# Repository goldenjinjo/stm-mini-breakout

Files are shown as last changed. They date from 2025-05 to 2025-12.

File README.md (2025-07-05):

# stm-mini-breakout
Breakout board for STM32H723ZGT6 MCU. Powered and programmed via USB C (FS). WIP.

Demonstration board for high-powered STM32s. 

## Schematics

# MCU
HX‑1 Schematic

# Communication and Power
HX-1 Communication and Power

# Filtering, HSE Clock and Mounting Holes
HX-1 Filtering, Clock and Mounting Holes

## PCB Layout
<p align="center">
HX-1 PCB Layout
</p>

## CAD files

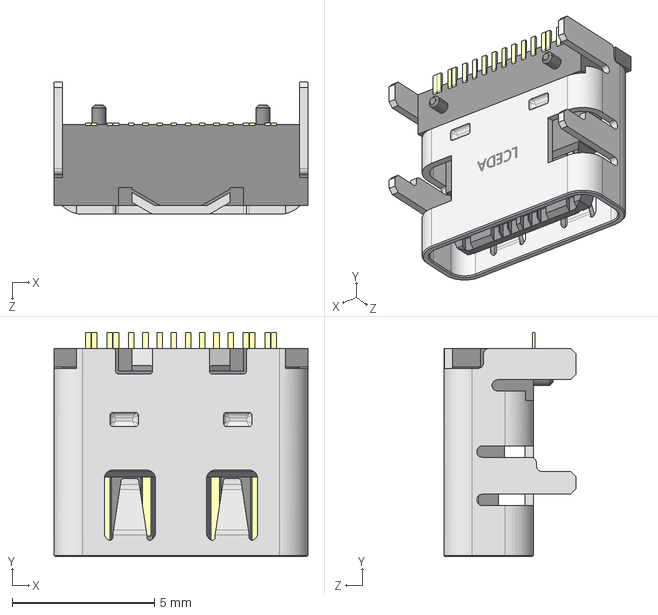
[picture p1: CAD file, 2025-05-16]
HX-1/component_libraries/3D_models/USB-C-SMD_G-SWITCH_GT-USB-7010ASV.step
8.94 x 7.90 x 4.66 mm

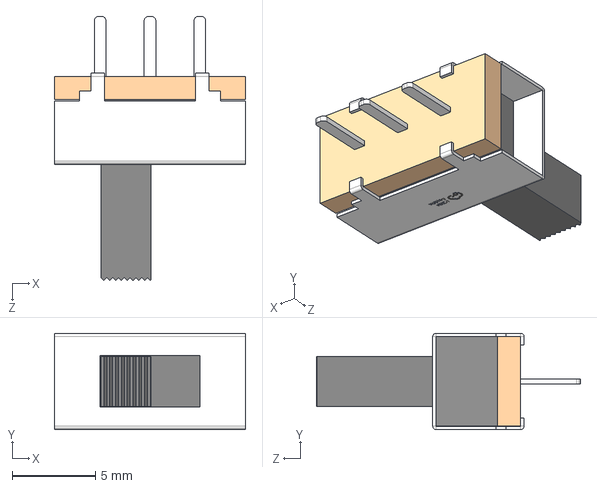
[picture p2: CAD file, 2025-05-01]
HX-1/component_libraries/3D_models/SW-TH_G-SWITCH_SS-12F20-G070.step
11.5 x 5.81 x 15.9 mm

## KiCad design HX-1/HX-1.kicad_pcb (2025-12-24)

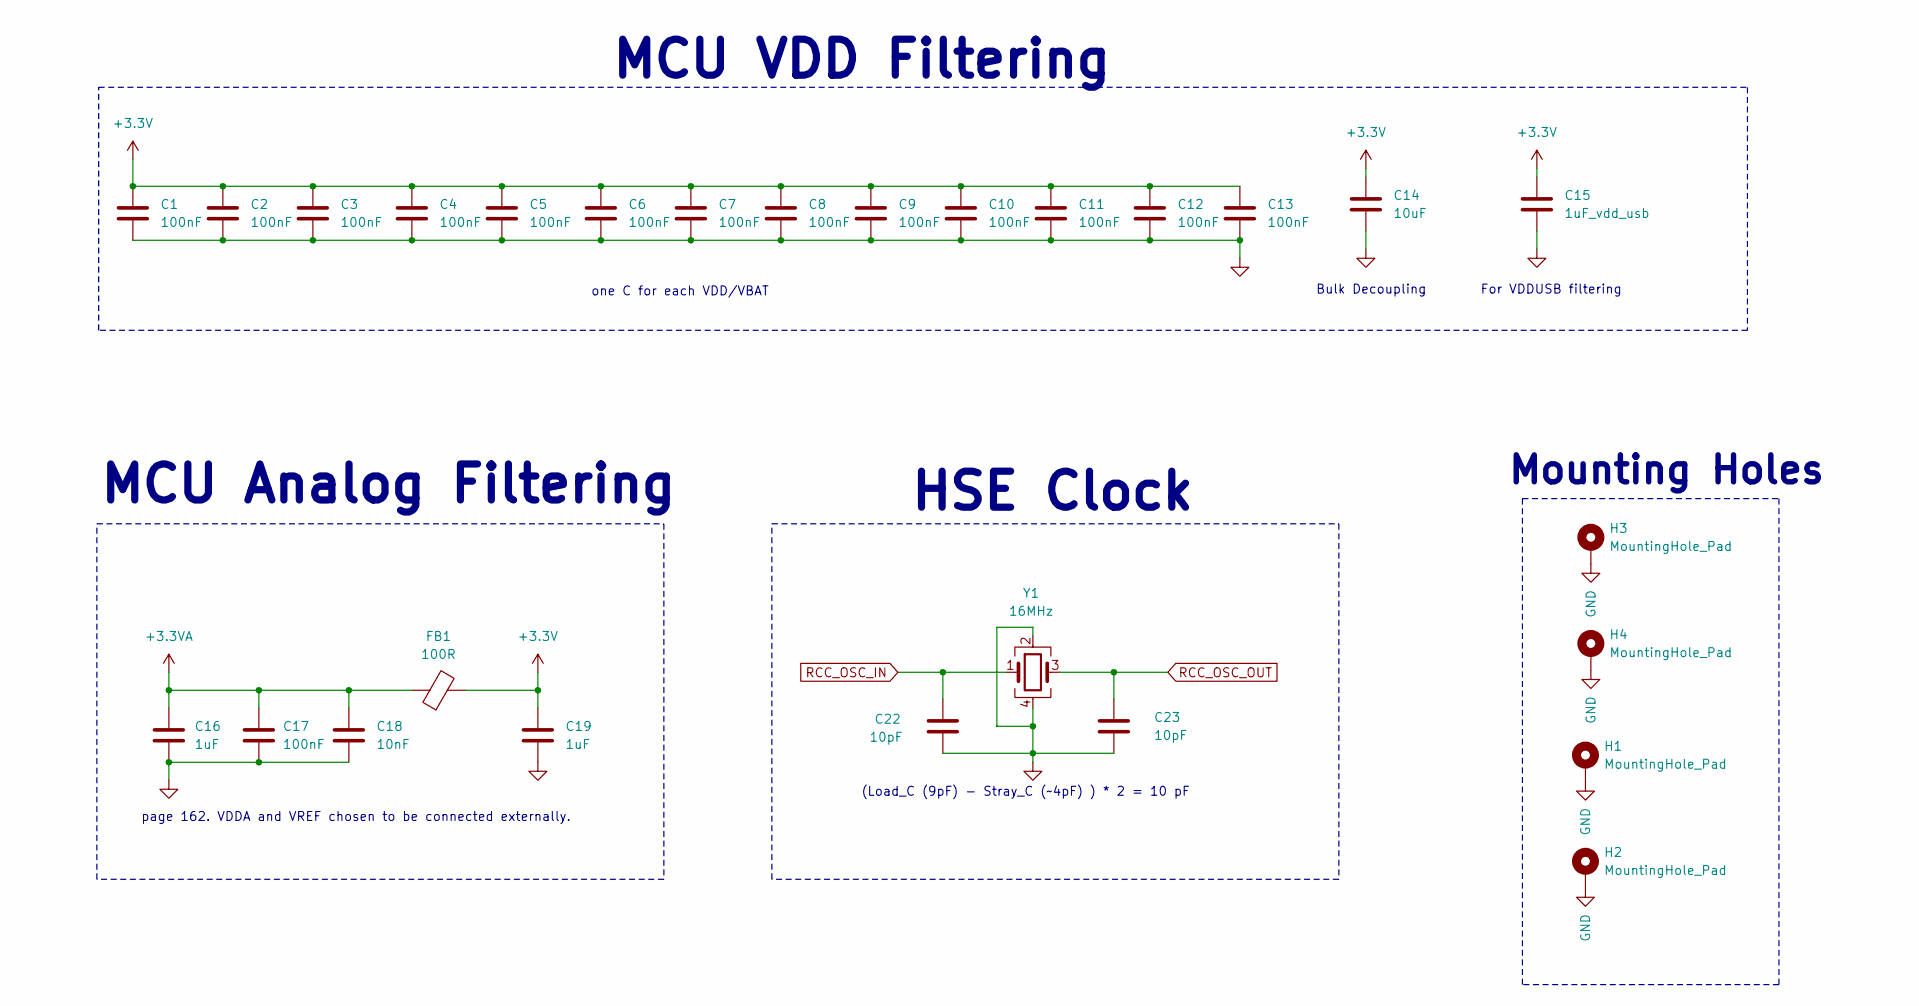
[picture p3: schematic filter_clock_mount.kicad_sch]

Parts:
C1, C2, C3, C4, C5, C6, C7, C8, C9, C10, C11, C12, C13, C17: 100nF; C_0402_1005Metric; LCSC PN C1525
C14: 10uF; C_0603_1608Metric; LCSC PN C19702
C15: 1uF_vdd_usb; C_0603_1608Metric; LCSC PN C15849
C16, C19: 1uF; C_0402_1005Metric; LCSC PN C52923
C18: 10nF; C_0603_1608Metric; LCSC PN C173276
C22, C23: 10pF; C_0603_1608Metric; LCSC PN C1634
FB1: 100R; R_0805_2012Metric; LCSC PN C1015
H1, H2, H3, H4: MountingHole_Pad; MountingHole_3.2mm_M3_Pad
Y1: 16MHz; Crystal_SMD_3225-4Pin_3.2x2.5mm; LCSC PN C13738

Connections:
+3.3V: C1.1, C2.1, C3.1, C4.1, C5.1, C6.1, C7.1, C8.1, C9.1, C10.1, C11.1, C12.1, C13.1, C14.1, C15.1, C19.1, FB1.2; also elsewhere on the board
+3.3VA: C16.1, C17.1, C18.1, FB1.1; also elsewhere on the board
GND: C1.2, C2.2, C3.2, C4.2, C5.2, C6.2, C7.2, C8.2, C9.2, C10.2, C11.2, C12.2, C13.2, C14.2, C15.2, C16.2, C17.2, C18.2, C19.2, C22.1, C23.2, H1.1, H2.1, H3.1, H4.1, Y1.2, Y1.4; also elsewhere on the board
RCC_OSC_IN: C22.2, Y1.1; also elsewhere on the board
RCC_OSC_OUT: C23.1, Y1.3; also elsewhere on the board

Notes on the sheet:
Bulk Decoupling
MCU Analog Filtering
page 162. VDDA and VREF chosen to be connected externally.
(Load_C (9pF) - Stray_C (~4pF) ) * 2 = 10 pF
one C for each VDD/VBAT
For VDDUSB filtering
HSE Clock
MCU VDD Filtering
Mounting Holes

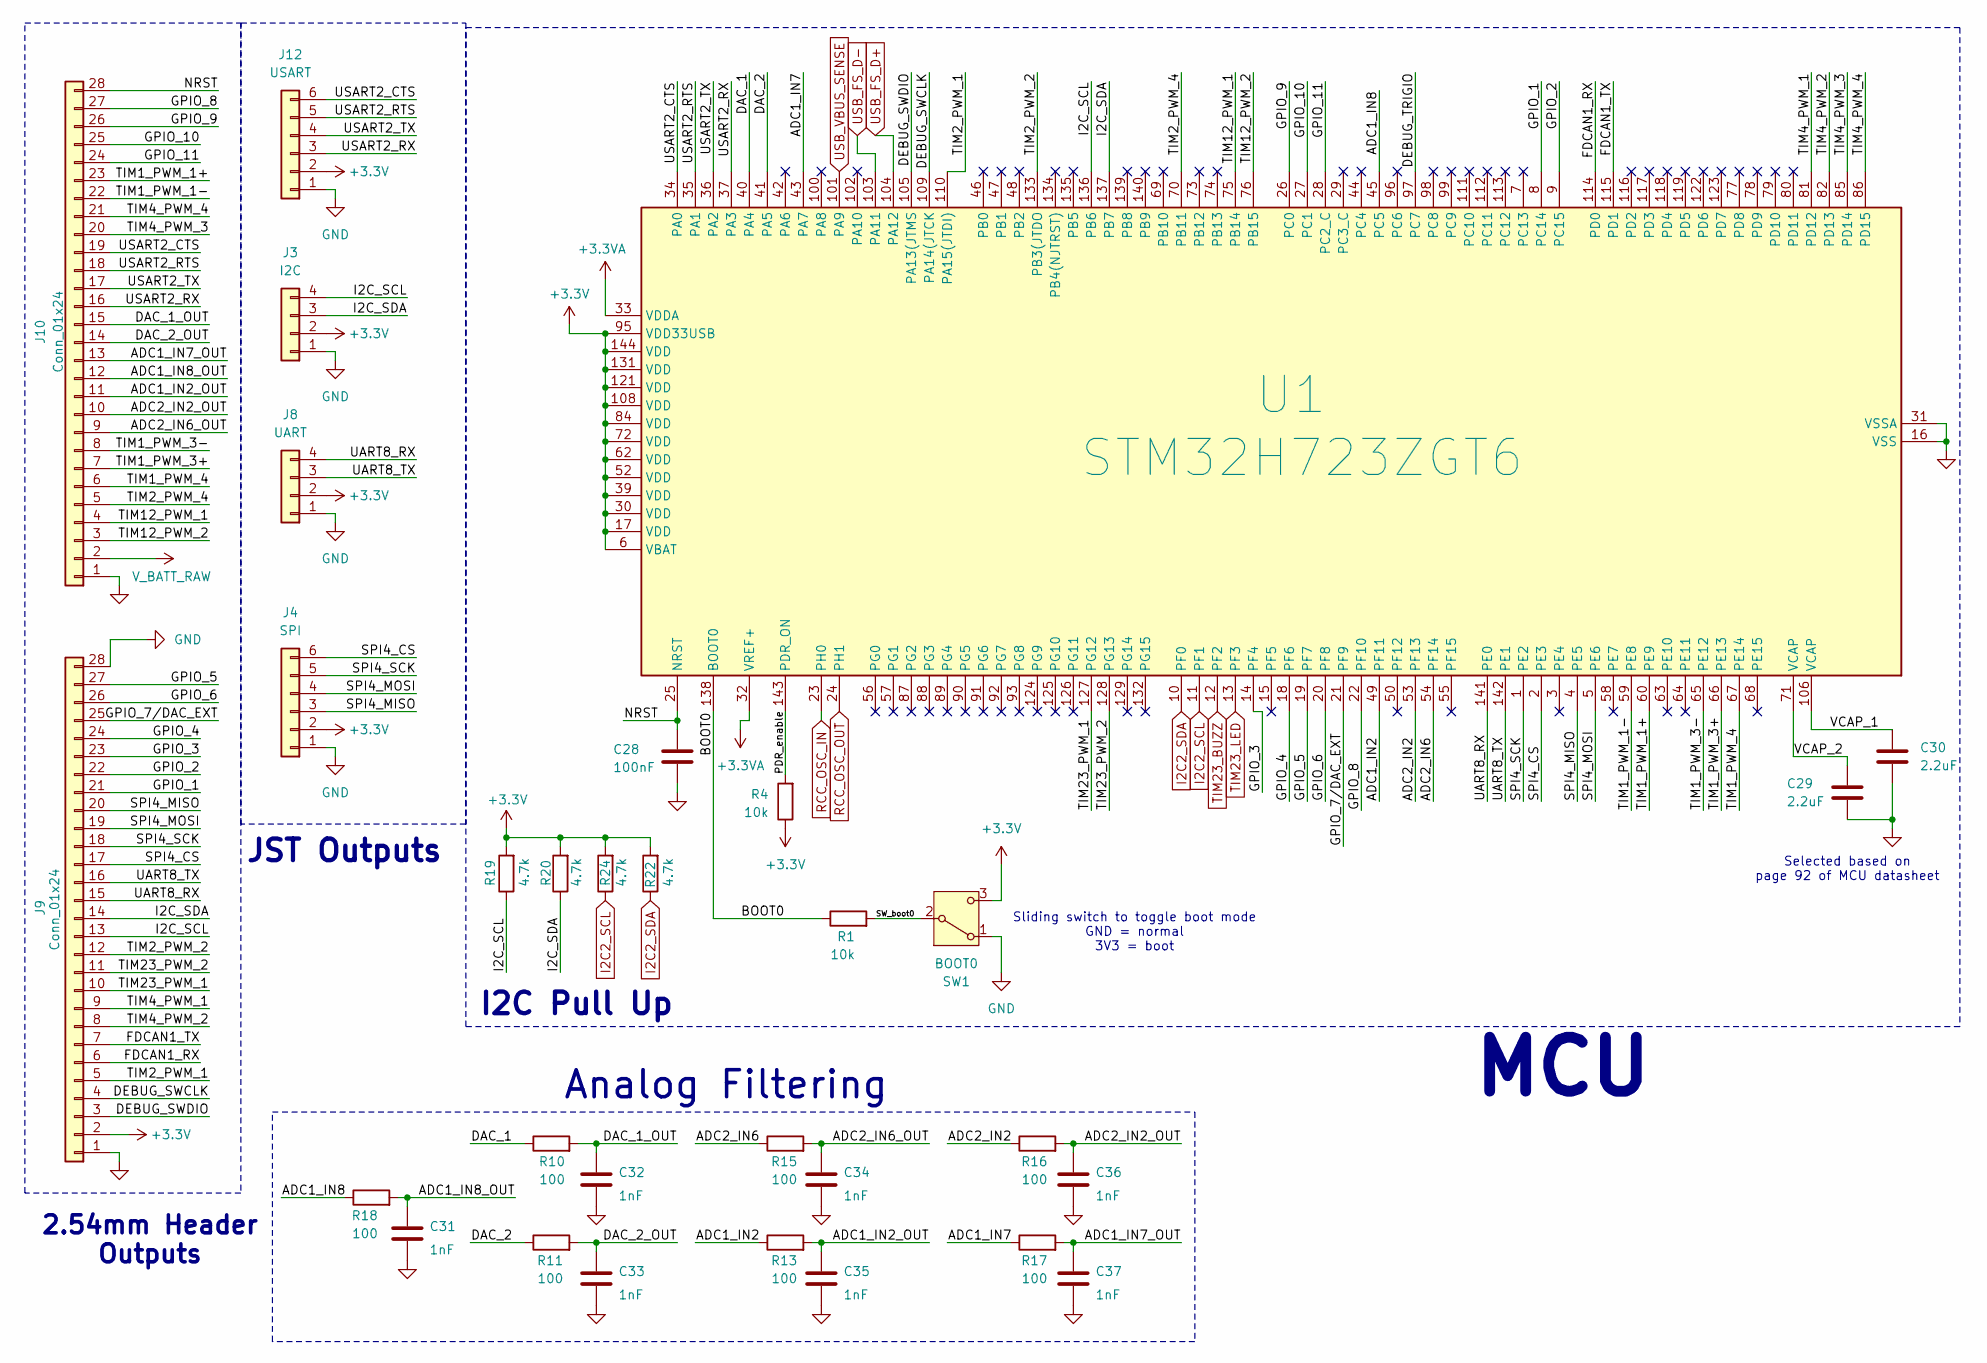
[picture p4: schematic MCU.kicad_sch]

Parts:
C28: 100nF; C_0402_1005Metric; LCSC PN C1525
C29, C30: 2.2uF; C_0603_1608Metric; LCSC PN C23630
C31, C32, C33, C34, C35, C36, C37: 1nF; C_0603_1608Metric; LCSC PN C1588
J3: I2C; JST_PH_B4B-PH-K_1x04_P2.00mm_Vertical; LCSC PN C131334
J4: SPI; JST_PH_B6B-PH-K_1x06_P2.00mm_Vertical; LCSC PN C131342
J8: UART; JST_PH_B4B-PH-K_1x04_P2.00mm_Vertical; LCSC PN C131334
J9, J10: Conn_01x24; PinHeader_1x28_P2.54mm_Vertical
J12: USART; JST_PH_B6B-PH-K_1x06_P2.00mm_Vertical; LCSC PN C131342
R1, R4: 10k; R_0402_1005Metric; LCSC PN C25744
R10, R11, R13, R15, R16, R17, R18: 100; R_0402_1005Metric; LCSC PN C25076
R19, R20, R22, R24: 4.7k; R_0402_1005Metric; LCSC PN C25900
SW1: BOOT0; SW-TH_G-SWITCH_SS-12F20-G070; LCSC PN C2848914
U1: STM32H723ZGT6; LQFP-144_20x20mm_P0.5mm; LCSC PN C730146

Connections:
+3.3V: J3.2, J4.2, J8.2, J9.2, J12.2, R4.1, R19.2, R20.2, R22.2, R24.2, SW1.3 (C), U1.6 (VBAT), U1.17 (VDD), U1.30 (VDD), U1.39 (VDD), U1.52 (VDD), U1.62 (VDD), U1.72 (VDD), U1.84 (VDD), U1.95 (VDD33USB), U1.108 (VDD), U1.121 (VDD), U1.131 (VDD), U1.144 (VDD); also elsewhere on the board
+3.3VA: U1.32 (VREF+), U1.33 (VDDA); also elsewhere on the board
/MCU/ADC1_IN2: R13.1, U1.49 (PF11)
/MCU/ADC1_IN2_OUT: C35.1, J10.11, R13.2
/MCU/ADC1_IN7: R17.1, U1.43 (PA7)
/MCU/ADC1_IN7_OUT: C37.1, J10.13, R17.2
/MCU/ADC1_IN8: R18.1, U1.45 (PC5)
/MCU/ADC1_IN8_OUT: C31.1, J10.12, R18.2
/MCU/ADC2_IN2: R16.1, U1.53 (PF13)
/MCU/ADC2_IN2_OUT: C36.1, J10.10, R16.2
/MCU/ADC2_IN6: R15.1, U1.54 (PF14)
/MCU/ADC2_IN6_OUT: C34.1, J10.9, R15.2
/MCU/BOOT0: R1.1, U1.138 (BOOT0)
/MCU/DAC_1: R10.1, U1.40 (PA4)
/MCU/DAC_1_OUT: C32.1, J10.15, R10.2
/MCU/DAC_2: R11.1, U1.41 (PA5)
/MCU/DAC_2_OUT: C33.1, J10.14, R11.2
/MCU/DEBUG_SWCLK: J9.4, U1.109 (PA14(JTCK)
/MCU/DEBUG_SWDIO: J9.3, U1.105 (PA13(JTMS)
/MCU/DEBUG_TRIGIO: U1.97 (PC7)
/MCU/FDCAN1_RX: J9.6, U1.114 (PD0)
/MCU/FDCAN1_TX: J9.7, U1.115 (PD1)
/MCU/GPIO_1: J9.21, U1.8 (PC14)
/MCU/GPIO_2: J9.22, U1.9 (PC15)
/MCU/GPIO_3: J9.23, U1.14 (PF4)
/MCU/GPIO_4: J9.24, U1.18 (PF6)
/MCU/GPIO_5: J9.27, U1.19 (PF7)
/MCU/GPIO_6: J9.26, U1.20 (PF8)
/MCU/GPIO_7/DAC_EXT: J9.25, U1.21 (PF9)
/MCU/GPIO_8: J10.27, U1.22 (PF10)
/MCU/GPIO_9: J10.26, U1.26 (PC0)
/MCU/GPIO_10: J10.25, U1.27 (PC1)
/MCU/GPIO_11: J10.24, U1.28 (PC2_C)
/MCU/I2C_SCL: J3.4, J9.13, R19.1, U1.136 (PB6)
/MCU/I2C_SDA: J3.3, J9.14, R20.1, U1.137 (PB7)
/MCU/NRST: C28.1, J10.28, U1.25 (NRST)
/MCU/PDR_enable: R4.2, U1.143 (PDR_ON)
/MCU/SPI4_CS: J4.6, J9.17, U1.2 (PE3)
/MCU/SPI4_MISO: J4.3, J9.20, U1.4 (PE5)
/MCU/SPI4_MOSI: J4.4, J9.19, U1.5 (PE6)
/MCU/SPI4_SCK: J4.5, J9.18, U1.1 (PE2)
/MCU/SW_boot0: R1.2, SW1.2 (B)
/MCU/TIM1_PWM_1+: J10.23, U1.60 (PE9)
/MCU/TIM1_PWM_1-: J10.22, U1.59 (PE8)
/MCU/TIM1_PWM_3+: J10.7, U1.66 (PE13)
/MCU/TIM1_PWM_3-: J10.8, U1.65 (PE12)
/MCU/TIM1_PWM_4: J10.6, U1.67 (PE14)
/MCU/TIM2_PWM_1: J9.5, U1.110 (PA15(JTDI))
/MCU/TIM2_PWM_2: J9.12, U1.133 (PB3(JTDO)
/MCU/TIM2_PWM_4: J10.5, U1.70 (PB11)
/MCU/TIM4_PWM_1: J9.9, U1.81 (PD12)
/MCU/TIM4_PWM_2: J9.8, U1.82 (PD13)
/MCU/TIM4_PWM_3: J10.20, U1.85 (PD14)
/MCU/TIM4_PWM_4: J10.21, U1.86 (PD15)
/MCU/TIM12_PWM_1: J10.4, U1.75 (PB14)
/MCU/TIM12_PWM_2: J10.3, U1.76 (PB15)
/MCU/TIM23_PWM_1: J9.10, U1.127 (PG12)
/MCU/TIM23_PWM_2: J9.11, U1.128 (PG13)
/MCU/UART8_RX: J8.4, J9.15, U1.141 (PE0)
/MCU/UART8_TX: J8.3, J9.16, U1.142 (PE1)
/MCU/USART2_CTS: J10.19, J12.6, U1.34 (PA0)
/MCU/USART2_RTS: J10.18, J12.5, U1.35 (PA1)
/MCU/USART2_RX: J10.16, J12.3, U1.37 (PA3)
/MCU/USART2_TX: J10.17, J12.4, U1.36 (PA2)
/MCU/VCAP_1: C30.1, U1.106 (VCAP)
/MCU/VCAP_2: C29.1, U1.71 (VCAP)
GND: C28.2, C29.2, C30.2, C31.2, C32.2, C33.2, C34.2, C35.2, C36.2, C37.2, J3.1, J4.1, J8.1, J9.1, J9.28, J10.1, J12.1, SW1.1 (A), U1.16 (VSS), U1.31 (VSSA), U1.38 (VSS), U1.51 (VSS), U1.61 (VSS), U1.83 (VSS), U1.94 (VSS), U1.107 (VSS), U1.120 (VSS), U1.130 (VSS); also elsewhere on the board
I2C2_SCL: R24.1, U1.11 (PF1); also elsewhere on the board
I2C2_SDA: R22.1, U1.10 (PF0); also elsewhere on the board
RCC_OSC_IN: U1.23 (PH0); also elsewhere on the board
RCC_OSC_OUT: U1.24 (PH1); also elsewhere on the board
TIM23_BUZZ: U1.12 (PF2); also elsewhere on the board
TIM23_LED: U1.13 (PF3); also elsewhere on the board
USB_FS_D+: U1.104 (PA12); also elsewhere on the board
USB_FS_D-: U1.103 (PA11); also elsewhere on the board
USB_VBUS_SENSE: U1.101 (PA9); also elsewhere on the board
V_BATT_RAW: J10.2; also elsewhere on the board

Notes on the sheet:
JST Outputs
2.54mm Header Outputs
MCU
Sliding switch to toggle boot mode GND = normal 3V3 = boot
I2C Pull Up
Analog Filtering
Selected based on page 92 of MCU datasheet

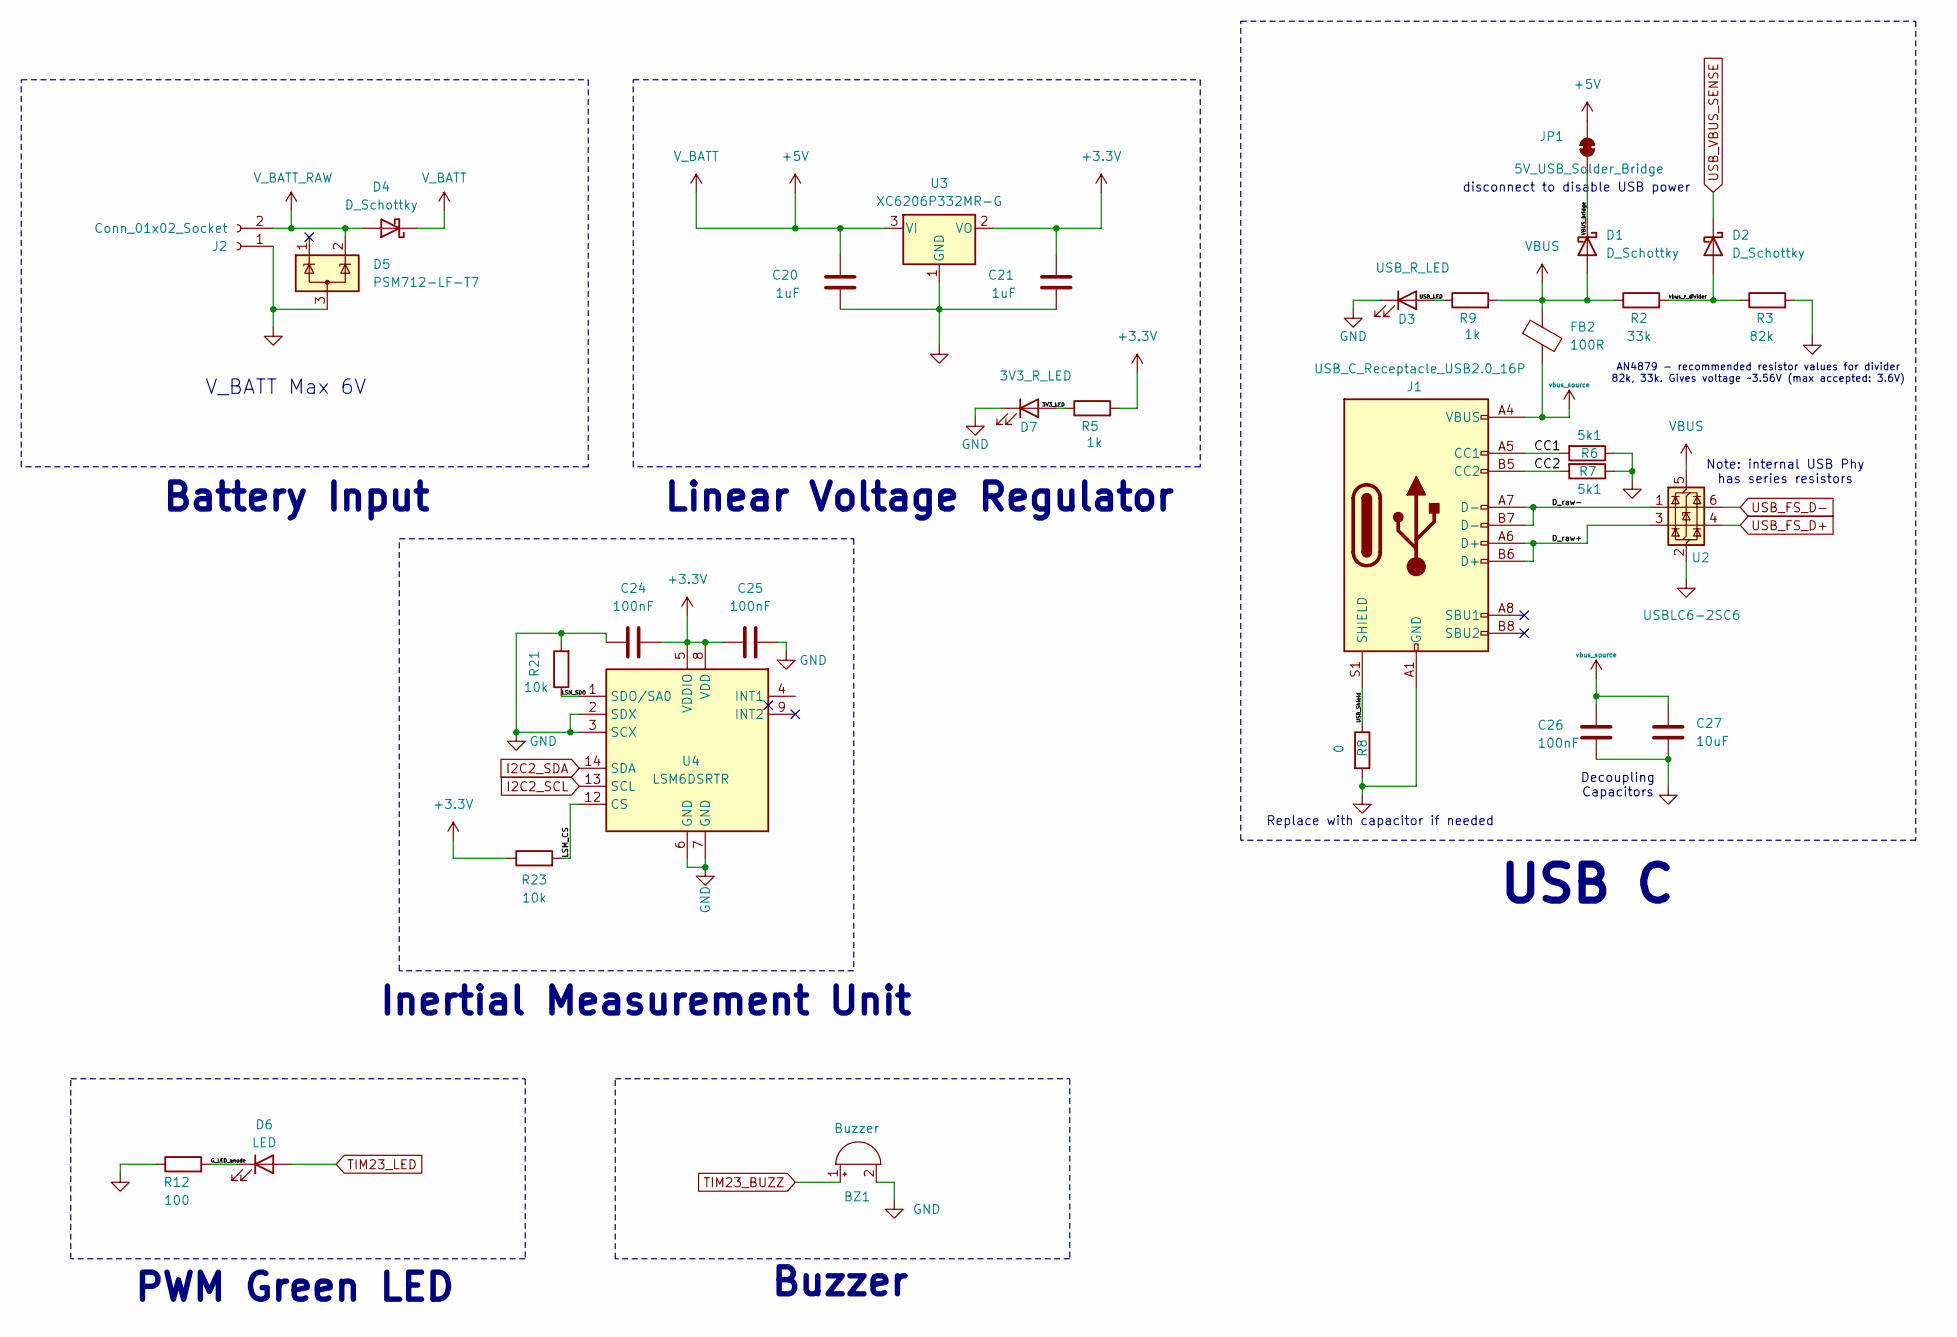
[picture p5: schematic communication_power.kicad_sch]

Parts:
BZ1: Buzzer; YUEXIN YX-SMD5020; LCSC PN C781883
C20, C21: 1uF; C_0402_1005Metric; LCSC PN C52923
C24, C25, C26: 100nF; C_0402_1005Metric; LCSC PN C1525
C27: 10uF; C_0603_1608Metric; LCSC PN C19702
D1, D2, D4: D_Schottky; D_SOD-323; LCSC PN C191023
D3: USB_R_LED; LED_0603_1608Metric; LCSC PN C2286
D5: PSM712-LF-T7; SOT-23-3; LCSC PN C32677
D6: LED; LED_0805_2012Metric; LCSC PN C2297
D7: 3V3_R_LED; LED_0603_1608Metric; LCSC PN C2286
FB2: 100R; R_0805_2012Metric; LCSC PN C1015
J1: USB_C_Receptacle_USB2.0_16P; USB_C_Receptacle_G-Switch_GT-USB-7010ASV; LCSC PN C2988369
J2: Conn_01x02_Socket; JST_PH_B2B-PH-K_1x02_P2.00mm_Vertical; LCSC PN C131337
JP1: 5V_USB_Solder_Bridge; SolderJumper-2_P1.3mm_Bridged_RoundedPad1.0x1.5mm
R2: 33k; R_0603_1608Metric; LCSC PN C4216
R3: 82k; R_0603_1608Metric; LCSC PN C23254
R5, R9: 1k; R_0603_1608Metric; LCSC PN C21190
R6, R7: 5k1; R_0603_1608Metric; LCSC PN C23186
R8: 0; R_0603_1608Metric; LCSC PN C21189
R12: 100; R_0402_1005Metric; LCSC PN C25076
R21, R23: 10k; R_0402_1005Metric; LCSC PN C25744
U2: USBLC6-2SC6; SOT-23-6; LCSC PN C7519
U3: XC6206P332MR-G; SOT-23-3; LCSC PN C5446
U4: LSM6DSRTR; LGA-14_3x2.5mm_P0.5mm_LayoutBorder3x4y; LCSC PN C784817

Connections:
+3.3V: C21.2, C24.2, C25.1, R5.2, R23.1, U3.2 (VO), U4.5 (VDDIO), U4.8 (VDD); also elsewhere on the board
+5V: C20.2, D4.1 (K), JP1.2 (B), U3.3 (VI)
/Communication and Power/3V3_LED: D7.2 (A), R5.1
/Communication and Power/CC1: J1.A5 (CC1), R6.2
/Communication and Power/CC2: J1.B5 (CC2), R7.2
/Communication and Power/D_raw+: J1.A6 (D+), J1.B6 (D+), U2.3 (I/O2)
/Communication and Power/D_raw-: J1.A7 (D-), J1.B7 (D-), U2.1 (I/O1)
/Communication and Power/G_LED_anode: D6.1 (K), R12.2
/Communication and Power/LSM_CS: R23.2, U4.12 (CS)
/Communication and Power/LSM_SDO: R21.1, U4.1 (SDO/SA0)
/Communication and Power/USB_LED: D3.2 (A), R9.1
/Communication and Power/USB_Shield: J1.S1 (SHIELD), R8.1
/Communication and Power/VBUS_bridge: D1.1 (K), JP1.1 (A)
/Communication and Power/vbus_r_divider: D2.2 (A), R2.2, R3.1
GND: BZ1.2 (+), C20.1, C21.1, C24.1, C25.2, C26.2, C27.2, D3.1 (K), D5.3 (A), D7.1 (K), J1.A1 (GND), J1.A12 (GND), J1.B1 (GND), J1.B12 (GND), J2.1, R3.2, R6.1, R7.1, R8.2, R12.1, R21.2, U2.2 (GND), U3.1 (GND), U4.2 (SDX), U4.3 (SCX), U4.6 (GND), U4.7 (GND); also elsewhere on the board
I2C2_SCL: U4.13 (SCL); also elsewhere on the board
I2C2_SDA: U4.14 (SDA); also elsewhere on the board
TIM23_BUZZ: BZ1.1 (-); also elsewhere on the board
TIM23_LED: D6.2 (A); also elsewhere on the board
USB_FS_D+: U2.4 (I/O2); also elsewhere on the board
USB_FS_D-: U2.6 (I/O1); also elsewhere on the board
USB_VBUS_SENSE: D2.1 (K); also elsewhere on the board
VBUS: D1.2 (A), FB2.1, R2.1, R9.2, U2.5 (VBUS)
V_BATT_RAW: D4.2 (A), D5.2 (K), J2.2; also elsewhere on the board
vbus_source: C26.1, C27.1, FB2.2, J1.A4 (VBUS), J1.A9 (VBUS), J1.B4 (VBUS), J1.B9 (VBUS)

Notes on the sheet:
PWM Green LED
Battery Input
V_BATT Max 6V
Linear Voltage Regulator
Replace with capacitor if needed
AN4879 - recommended resistor values for divider 82k, 33k. Gives voltage ~3.56V (max accepted: 3.6V)
Decoupling Capacitors
Buzzer
disconnect to disable USB power
Inertial Measurement Unit
Note: internal USB Phy has series resistors
USB C

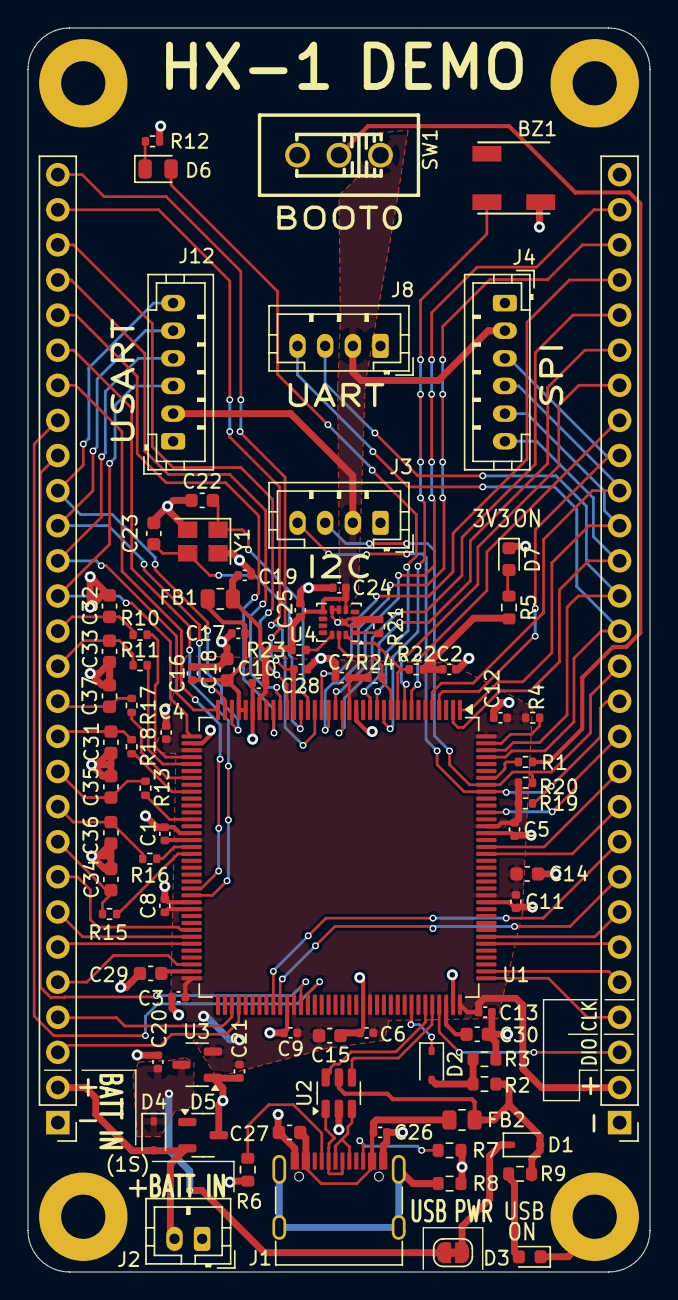
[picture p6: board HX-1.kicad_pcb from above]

Board: 2 copper layers, 45.0 x 90.0 mm, 89 parts (0 on the bottom side), 91 nets.

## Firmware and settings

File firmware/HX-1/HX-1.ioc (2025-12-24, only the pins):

Mcu.UserName=STM32H723ZGTx
PA0.Signal=USART2_CTS
PA1.Signal=USART2_RTS
PA10.Signal=GPIO_Analog
PA11.Signal=USB_OTG_HS_DM
PA12.Signal=USB_OTG_HS_DP
PA13(JTMS/SWDIO).Signal=DEBUG_JTMS-SWDIO
PA14(JTCK/SWCLK).Signal=DEBUG_JTCK-SWCLK
PA15(JTDI).Signal=S_TIM2_CH1_ETR
PA2.Signal=USART2_TX
PA3.Signal=USART2_RX
PA4.Signal=COMP_DAC11_group
PA5.Signal=COMP_DAC12_group
PA6.Signal=GPIO_Analog
PA7.Signal=ADCx_INP7
PA8.Signal=GPIO_Analog
PA9.Signal=USB_OTG_HS_VBUS
PB0.Signal=GPIO_Analog
PB1.Signal=GPIO_Analog
PB10.Signal=GPIO_Analog
PB11.Signal=S_TIM2_CH4
PB13.Signal=GPIO_Analog
PB14.Signal=S_TIM12_CH1
PB15.Signal=S_TIM12_CH2
PB2.Signal=GPIO_Analog
PB3(JTDO/TRACESWO).Signal=S_TIM2_CH2
PB4(NJTRST).Signal=GPIO_Analog
PB5.Signal=GPIO_Analog
PB6.Signal=I2C1_SCL
PB7.Signal=I2C1_SDA
PB8.Signal=GPIO_Analog
PB9.Signal=GPIO_Analog
PC0.GPIO_Label=GPIO_9
PC0.Signal=GPIO_Output
PC1.GPIO_Label=GPIO_10
PC1.Signal=GPIO_Output
PC10.Signal=GPIO_Analog
PC11.Signal=GPIO_Analog
PC12.Signal=GPIO_Analog
PC13.Signal=GPIO_Analog
PC14-OSC32_IN.GPIO_Label=GPIO_1
PC14-OSC32_IN.Signal=GPIO_Output
PC15-OSC32_OUT.GPIO_Label=GPIO_2
PC15-OSC32_OUT.Signal=GPIO_Output
PC2_C.GPIO_Label=GPIO_11
PC2_C.Signal=GPIO_Output
PC3_C.Signal=GPIO_Analog
PC4.Signal=GPIO_Analog
PC5.Signal=ADCx_INP8
PC6.Signal=GPIO_Analog
PC7.Signal=DEBUG_TRGIO
PC8.Signal=GPIO_Analog
PC9.Signal=GPIO_Analog
PD0.Signal=FDCAN1_RX
PD1.Signal=FDCAN1_TX
PD10.Signal=GPIO_Analog
PD11.Signal=GPIO_Analog
PD12.Signal=S_TIM4_CH1
PD13.Signal=S_TIM4_CH2
PD14.Signal=S_TIM4_CH3
PD15.Signal=S_TIM4_CH4
PD2.Signal=GPIO_Analog
PD3.Signal=GPIO_Analog
PD4.Signal=GPIO_Analog
PD5.Signal=GPIO_Analog
PD6.Signal=GPIO_Analog
PD7.Signal=GPIO_Analog
PD8.Signal=GPIO_Analog
PD9.Signal=GPIO_Analog
PE0.Signal=UART8_RX
PE1.Signal=UART8_TX
PE10.Signal=GPIO_Analog
PE11.Signal=GPIO_Analog
PE12.Signal=TIM1_CH3N
PE13.Signal=S_TIM1_CH3
PE14.Signal=S_TIM1_CH4
PE15.Signal=GPIO_Analog
PE2.Signal=SPI4_SCK
PE3.GPIO_Label=SPI4_CS
PE3.Signal=GPIO_Output
PE4.Signal=GPIO_Analog
PE5.Signal=SPI4_MISO
PE6.Signal=SPI4_MOSI
PE7.Signal=GPIO_Analog
PE8.Signal=TIM1_CH1N
PE9.Signal=S_TIM1_CH1
PF0.Signal=I2C2_SDA
PF1.Signal=I2C2_SCL
PF10.GPIO_Label=GPIO_8
PF10.Signal=GPIO_Output
PF11.Signal=ADC1_INP2
PF12.Signal=GPIO_Analog
PF13.Signal=ADC2_INP2
PF14.Signal=ADC2_INP6
PF15.Signal=GPIO_Analog
PF2.GPIO_Label=TIM23_BUZZ
PF2.Signal=S_TIM23_CH3
PF3.GPIO_Label=TIM23_LED
PF3.Signal=S_TIM23_CH4
PF4.GPIO_Label=GPIO_3
PF4.Signal=GPIO_Output
PF5.Signal=GPIO_Analog
PF6.GPIO_Label=GPIO_4
PF6.Signal=GPIO_Output
PF7.GPIO_Label=GPIO_5
PF7.Signal=GPIO_Output
PF8.GPIO_Label=GPIO_6
PF8.Signal=GPIO_Output
PF9.GPIO_Label=GPIO_7/DAC_EXT
PF9.Signal=GPIO_Output
PG0.Signal=GPIO_Analog
PG1.Signal=GPIO_Analog
PG10.Signal=GPIO_Analog
PG11.Signal=GPIO_Analog
PG12.Signal=TIM23_CH1
PG13.Signal=S_TIM23_CH2
PG14.Signal=GPIO_Analog
PG15.Signal=GPIO_Analog
PG2.Signal=GPIO_Analog
PG3.Signal=GPIO_Analog
PG4.Signal=GPIO_Analog
PG5.Signal=GPIO_Analog
PG6.Signal=GPIO_Analog
PG7.Signal=GPIO_Analog
PG8.Signal=GPIO_Analog
PG9.Signal=GPIO_Analog
PH0-OSC_IN.Signal=RCC_OSC_IN
PH1-OSC_OUT.Signal=RCC_OSC_OUT

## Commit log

2025-04-14 initial mcu selection and placement
    [HX-1.kicad_pcb, HX-1.kicad_sch]
2025-04-15 add more power circuitry
    [HX-1.kicad_pcb, HX-1.kicad_sch]
2025-04-15 add footprints and lcsc pn for all passive components so far
    [HX-1.kicad_pcb, HX-1.kicad_sch]
2025-04-16 add some vbus circuitry and pin mappings for communication systems on mcu
    [HX-1.kicad_pcb, HX-1.kicad_sch]
2025-04-16 add script to automatically save schematic.svg, update readme to reference schematic.svg
    [HX-1.kicad_pcb, HX-1.kicad_sch]
2025-04-22 add firmware, update ioc file and schematic to have values for all mcu pins
    [HX-1.kicad_pcb, HX-1.kicad_sch]
2025-04-22 change schematic image to upload straight into docs folder, fix not auto updating
    [HX-1.kicad_sch]
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2025-04-28 add crystal circuitry and dedicated sheets for comms and power
    [HX-1.kicad_pcb, HX-1.kicad_sch, communication_debug.kicad_sch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]
2025-04-28 move components to correct sheets, change net labels to global
    [HX-1.kicad_pcb, HX-1.kicad_sch, communication_debug.kicad_sch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]
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2025-04-28 add first draft of USB C design
    [HX-1.kicad_pcb, HX-1.kicad_sch, communication_debug.kicad_sch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]
2025-04-29 add LED and remaining footprints/LCSC PN to USB C circuit
    [HX-1.kicad_pcb, communication_debug.kicad_sch]
2025-04-29 add vbus filtering and voltage regululator for 3.3V
    [HX-1.kicad_pcb, communication_debug.kicad_sch, power_clock_io.kicad_sch]
2025-04-29 change almost all components to be basic jlcpcb parts
    [HX-1.kicad_pcb, HX-1.kicad_sch, communication_debug.kicad_sch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]
2025-04-29 add battery input circuit
    [HX-1.kicad_pcb, power_clock_io.kicad_sch]
2025-04-30 add mcu schematic file, change main to just link to other schematics. Update readme to show MCU schematic
    [HX-1.kicad_sch, MCU.kicad_sch]
2025-04-30 add buzzer, remove one ADC diff pair
    [HX-1.kicad_pcb, MCU.kicad_sch, communication_debug.kicad_sch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]
2025-04-30 remove uart7, spi2 and extra CS. Not needed. Start mapping GPIO
    [HX-1.kicad_pcb, MCU.kicad_sch, communication_debug.kicad_sch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]
2025-04-30 add jst connectors to comms, add imu, start structuring pcb
    [HX-1.kicad_pcb, MCU.kicad_sch, communication_debug.kicad_sch]
2025-04-30 change most passive components to 0402 to save space
    [HX-1.kicad_pcb, MCU.kicad_sch, communication_debug.kicad_sch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]
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2025-04-30 change analog resistors to 0402 to make routing easier
    [HX-1.kicad_pcb, MCU.kicad_sch, communication_debug.kicad_sch]
2025-05-01 update scripts to export pcb svg
    [HX-1.kicad_pcb, MCU.kicad_sch, power_clock_io.kicad_sch]
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2025-05-02 change schottky diode to basic part from jlcpcb
    [HX-1.kicad_pcb, communication_debug.kicad_sch, power_clock_io.kicad_sch]
2025-05-02 add 3v3 led and pwm led, position mounting holes and pin header
    [HX-1.kicad_pcb, MCU.kicad_sch, power_clock_io.kicad_sch]
2025-05-03 map out traces for all I/Os, remove some ADC, PWM and GPIO for space
    [HX-1.kicad_pcb, MCU.kicad_sch]
2025-05-03 change GPIO locations to optimise for output headers
    [HX-1.kicad_pcb, MCU.kicad_sch]
2025-05-03 clean up schematic, layout more of pcb, fix some footprints
    [HX-1.kicad_pcb, MCU.kicad_sch, communication_debug.kicad_sch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]
2025-05-16 add 3D model to usb
    [HX-1.kicad_pcb, USB-C-SMD_G-SWITCH_GT-USB-7010ASV.step]
2025-05-16 remove fdcan connector for space, add header debug pin
    [HX-1.kicad_pcb, MCU.kicad_sch, communication_debug.kicad_sch]
2025-05-16 increase board height to 90mm to give more space to jst connectors
    [HX-1.kicad_pcb, communication_debug.kicad_sch]
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2025-05-16 expand board width to 45mm to give space for component legends
    [HX-1.kicad_pcb]
2025-05-17 Position most of the passive components on pcb
    [HX-1.kicad_pcb, power_clock_io.kicad_sch]
2025-05-17 change USB capacitors to be fueled from VBUS_raw
    [HX-1.kicad_pcb, communication_debug.kicad_sch]
2025-05-17 complete initial placement of all components, trace 5V
    [HX-1.kicad_pcb]
2025-05-17 remove 8 pin header on top of board, extend side headers by 4 each to replace pins
    [HX-1.kicad_pcb, MCU.kicad_sch]
2025-05-17 remove GPIO 12 and DEBUG conn, add debug to right header
    [HX-1.kicad_pcb, MCU.kicad_sch]
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2025-05-17 remove 3V3 out and replace with standard 3V3 in.
    [HX-1.kicad_pcb, MCU.kicad_sch]
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2025-06-12 remove deprecated debug header, improve silkscreen pin designators
    [HX-1.kicad_pcb]
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2025-06-12 route missing 3v3 traces
    [HX-1.kicad_pcb]
2025-06-13 add 3v3 pour under MCU, complete routing of 3v3 traces
    [HX-1.kicad_pcb]
2025-06-13 route usb trace and fix 3v3 pours
    [HX-1.kicad_pcb]
2025-06-13 increase edge spacing to 4mm for mounting holes
    [HX-1.kicad_pcb]
2025-06-16 remove copper plot from svg to fix gnd plane blocking everything. route some signal traces
    [HX-1.kicad_pcb]
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2025-06-17 route USART traces, flip pin 18 and pin 19 on left header
    [HX-1.kicad_pcb, MCU.kicad_sch]
2025-06-17 route more of left side, change copper clearances based on jlcpcb
    [HX-1.kicad_pcb]
2025-06-17 fix hole clearances, write custom rule for USB C to stop mechanical hole clearance error
    [HX-1.kicad_pcb]
2025-06-17 remove silkscreen too close to pad on buzzer, adjust via for gnd plane
    [HX-1.kicad_pcb]
2025-06-17 complete route of left side of board, flip cts and rts pins on jst connector
    [HX-1.kicad_pcb, MCU.kicad_sch]
2025-06-17 rearrange some analog voltage components, connect missing 3v3 traces
    [HX-1.kicad_pcb]
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2025-06-17 replace right header pin for BOOT with GND, remove PIN control of BOOT for simplicity
    [HX-1.kicad_pcb, MCU.kicad_sch]
2025-06-19 adjust left side traces and components for better ground plane
    [HX-1.kicad_pcb]
2025-06-23 change pin ordering of SPI on left header for better routing, route some of the left traces
    [HX-1.kicad_pcb, MCU.kicad_sch]
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2025-06-23 remove unuused pull up resistor on D+ USB, too difficult to trace and unneccesary
    [HX-1.kicad_pcb, communication_debug.kicad_sch]
2025-06-23 flip TWM_PWM+1 and -1 for better routing, improve routing for better gnd planes
    [HX-1.kicad_pcb, MCU.kicad_sch]
2025-06-23 clean up left side traces, flip TWM1_PWM1 traces back as vias had them flipped
    [HX-1.kicad_pcb, MCU.kicad_sch]
2025-06-23 generally improve gnd plane, reduce min gnd plane width to 0.2mm
    [HX-1.kicad_pcb]
2025-06-23 further refine copper pours and traces, clean up Fab layer
    [HX-1.kicad_pcb]
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2025-07-05 tidy up schematics and change groupings on each sheet
    [MCU.kicad_sch, communication_debug.kicad_sch, power_clock_io.kicad_sch]
2025-07-05 change schematic file name and doc, script references
    [HX-1.kicad_sch, communication_debug.kicad_sch, communication_power.kicad_sch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]
2025-07-05 add bold text to filtering sch sheet :
    [filter_clock_mount.kicad_sch]
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2025-12-24 add an extra JLC to order number mark
    [HX-1.kicad_pcb]
2025-12-24 add assembly files, fix reference designators
    [HX-1.kicad_pcb, MCU.kicad_sch, communication_power.kicad_sch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]
2025-12-24 change LSM6DS to version compat with jlcpcb economic pcba
    [HX-1.kicad_pcb, communication_power.kicad_sch]
